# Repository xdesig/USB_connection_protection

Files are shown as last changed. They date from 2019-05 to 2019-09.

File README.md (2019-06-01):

# USB connection protection  V 001

This circuit is responsible for the protection against excessive consumption by resettable fuse and protection against overvoltage. to protect each I / O pin from high voltages, from ESD for electronic equipment that can be connected via the USB bus.
Rugged diodes (TVS Diode Arrays (SPA® Diodes) littelfuse) can safely absorb repetitive strokes of ESD at the maximum level specified in the international standard IEC 61000-4-2 (Level 4, contact discharge of ± 8 kV) without performance degradation. Their very low load capacity also makes them ideal for protecting high speed signal pins such as HDMI, DVI, USB2.0 and IEEE 1394.

Protects both the computer and the peripheral. I designed this small circuit when an improper mount of a driver in a RAMPS, burned the USB of the Laptop :-(

Buy PCB in [PCBWAY]

Components: Electronics Lcsc

[USB Female]

[USB Male]

PTC Resettable fuse [SMD1206B050TF]

TVS Littelfuse [SP3003-02JTG]

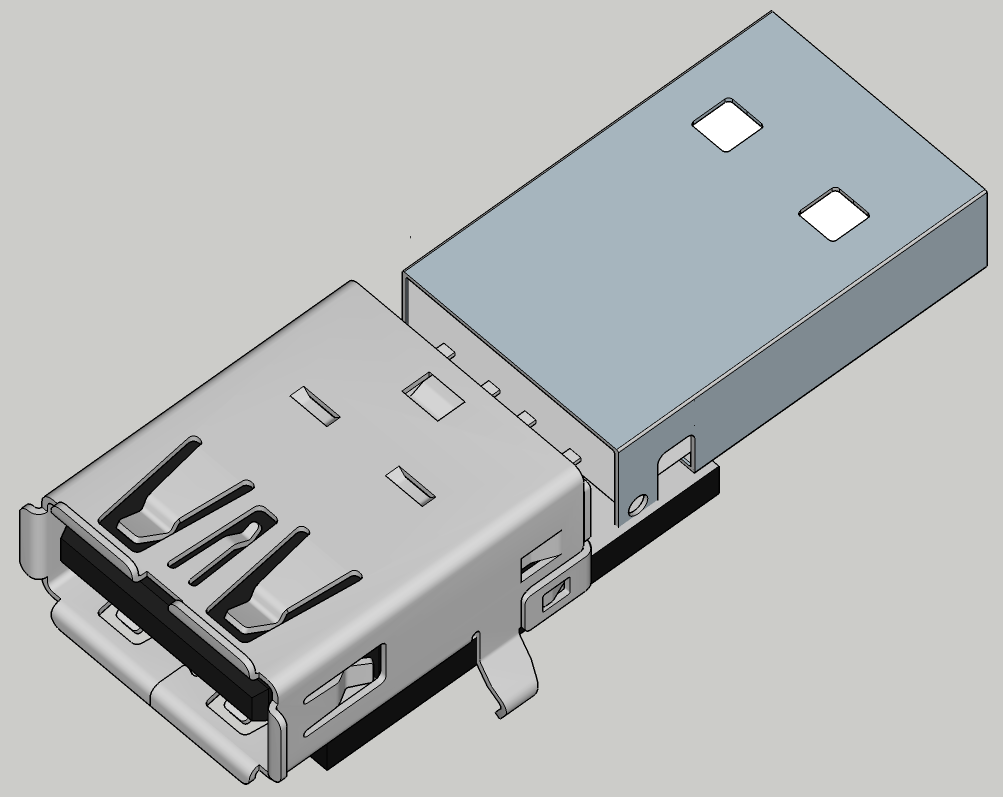
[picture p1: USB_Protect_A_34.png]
Render

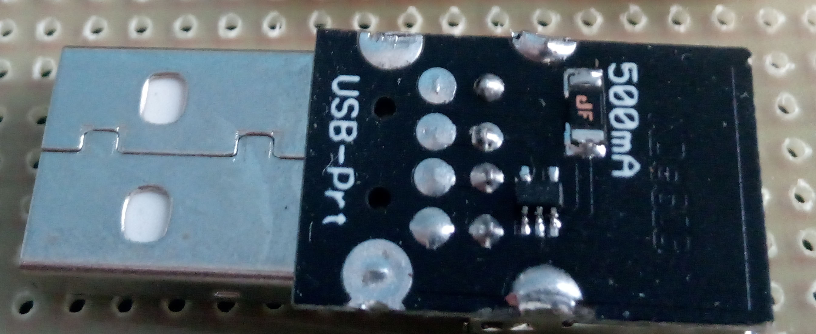
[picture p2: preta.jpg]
Real


## Author and license
* Author: [XDeSIG][TWI01]
* License: [Attribution-ShareAlike 4.0 International] [CCBY-SA4.0]

<!-- links -->

[CCBY-SA4.0]: http://creativecommons.org/licenses/by-sa/4.0/
[TWI01]: https://twitter.com/xdesig
[RENDER]: USB_Protect_A_34.png
[Real]: preta.jpg
[PCBWAY]: https://www.pcbway.com/project/shareproject/USB_connection_protection.html
[USB Female]: https://lcsc.com/product-detail/USB-Connectors_Jing-Extension-of-the-Electronic-Co-LCSC-USB-A-F900-14-1-Not-high-temperature_C2344.html
[USB Male]: https://lcsc.com/product-detail/USB-Connectors_Atype-USBMale-head-USB-05_C112454.html
[SMD1206B050TF]: https://lcsc.com/product-detail/Others_Brightking-Elec-TAIWAN-SMD1206B025TF_C269112.html
[SP3003-02JTG]: https://lcsc.com/product-detail/TVS_Littelfuse_SP3003-02JTG_SP3003-02JTG_C151302.html

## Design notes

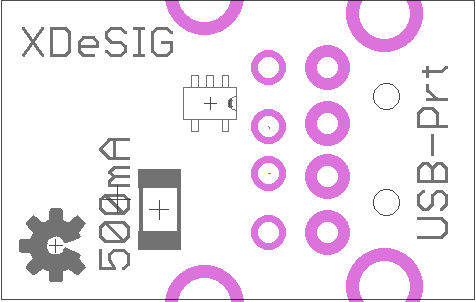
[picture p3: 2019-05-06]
USB_Protect_A_SB.png

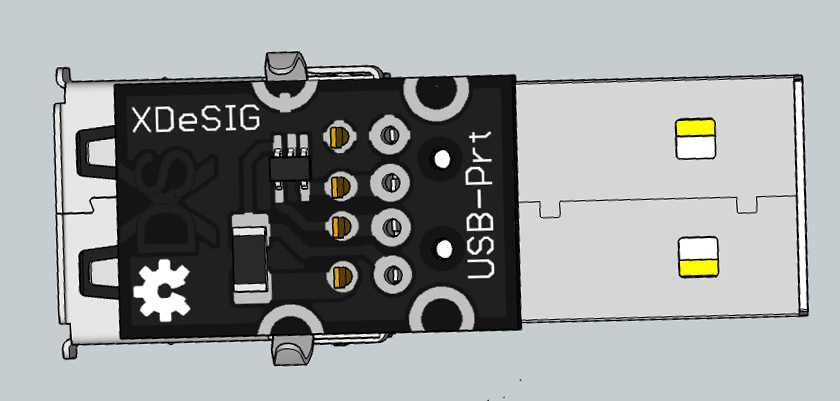
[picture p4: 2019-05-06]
USB_Protect_A_Bot.png

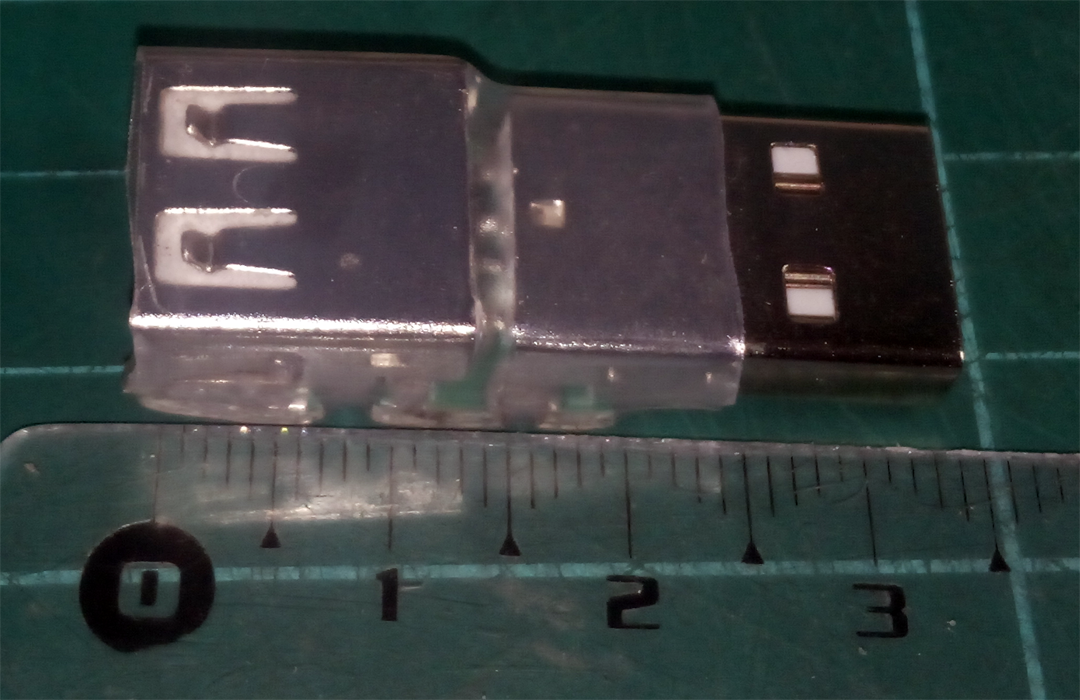
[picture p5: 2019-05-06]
USB_Protect_A_PTOP.png

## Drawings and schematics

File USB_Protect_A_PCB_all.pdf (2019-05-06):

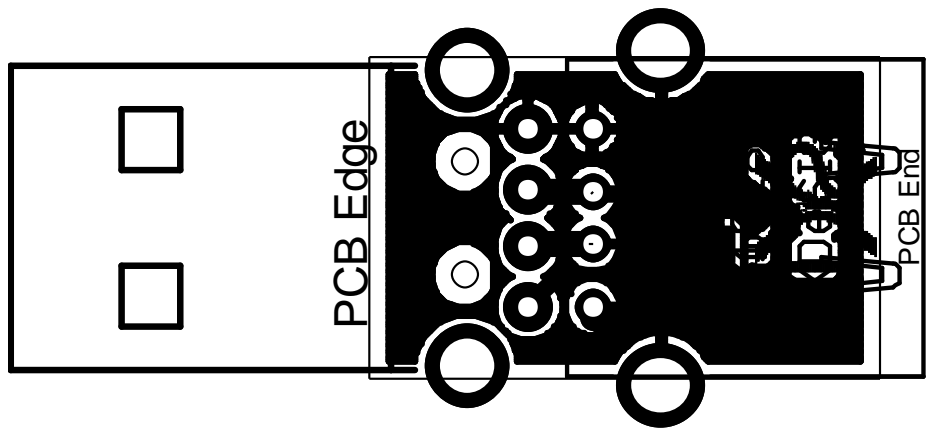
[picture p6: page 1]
PCB Edge; PCB End

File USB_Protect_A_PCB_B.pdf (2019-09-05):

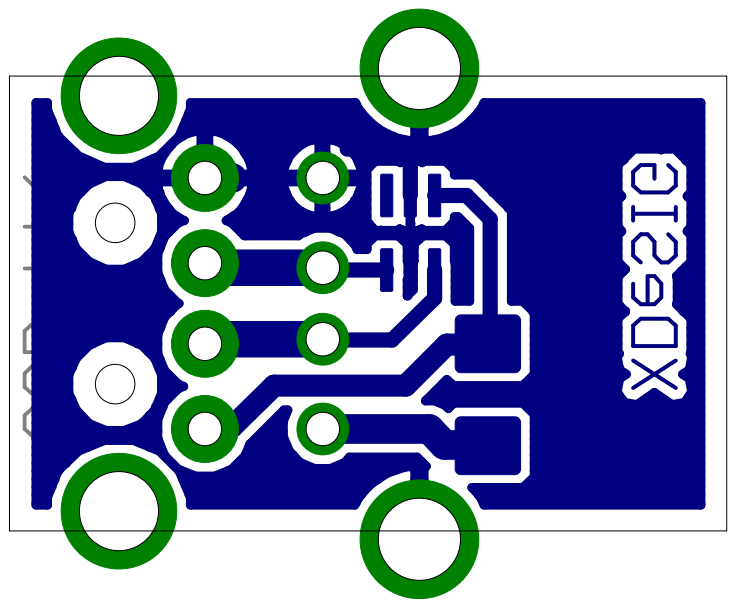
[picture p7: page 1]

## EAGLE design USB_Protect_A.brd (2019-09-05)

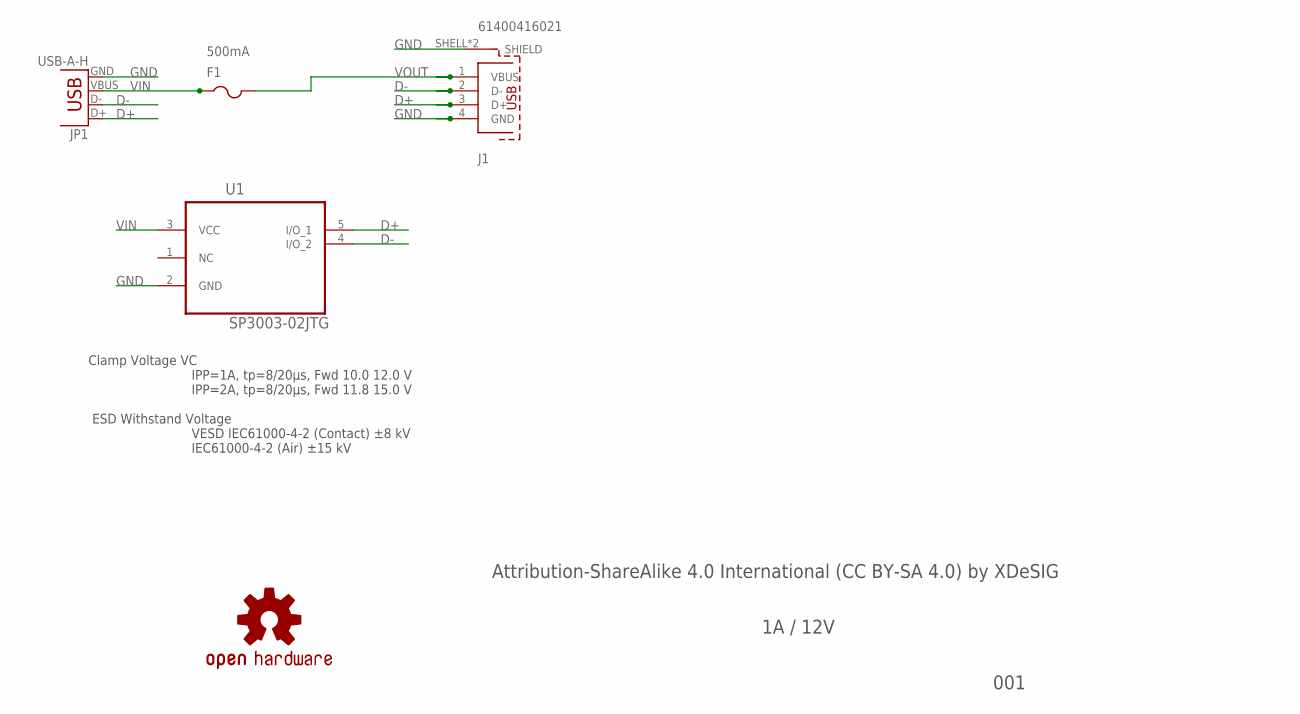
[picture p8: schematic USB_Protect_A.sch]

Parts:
F1: 500mA; R1206
J1: 61400416021
JP1: USB-A-H
LOGO1: OSHW-LOGOS; ESCORNA_LBRESCORNA_CPU_2_10_SPARKFUN-AESTHETICS_OSHW-LOGO-S
U1: SP3003-02JTG; SOT65P220X110-5N

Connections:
D+: J1.3 (D+), JP1.D+, U1.5 (I/O_1)
D-: J1.2 (D-), JP1.D-, U1.4 (I/O_2)
GND: J1.4 (GND), J1.SHELL (SHIELD), J1.SHELL1 (SHIELD), JP1.GND, U1.2 (GND)
VIN: F1.1, JP1.VBUS, U1.3 (VCC)
VOUT: F1.2, J1.1 (VBUS)

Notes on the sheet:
Clamp Voltage VC IPP=1A, tp=8/20µs, Fwd 10.0 12.0 V IPP=2A, tp=8/20µs, Fwd 11.8 15.0 V ESD Withstand Voltage VESD IEC61000-4-2 (Contact) ±8 kV IEC61000-4-2 (Air) ±15 kV
1A / 12V
Attribution-ShareAlike 4.0 International (CC BY-SA 4.0) by XDeSIG
001

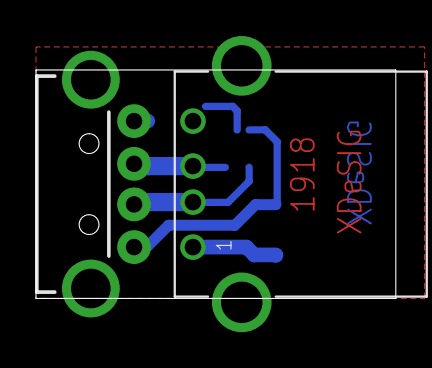
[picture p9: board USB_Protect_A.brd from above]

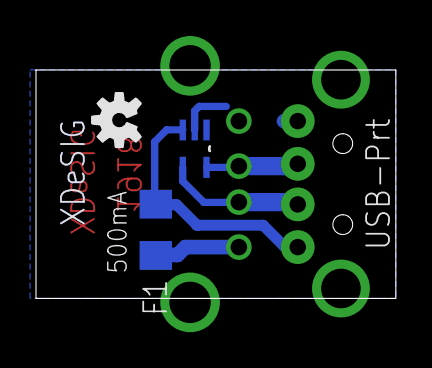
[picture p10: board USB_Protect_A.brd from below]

Board: 2 copper layers, 20.0 x 12.7 mm, 5 parts (3 on the bottom side), 5 nets.

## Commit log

2019-05-06 Inital commit
    Public
    [USB_Protect_A.sch]
2019-05-06 Revert "Inital commit"
    This reverts commit 5c7089dacc69489dbe68ce8c657147b81196c9f3.
    [USB_Protect_A.sch]
2019-05-06 Initial
    Initial commit
    [USB_Protect_A.sch]
2019-09-05 Update
    Update details
    [USB_Protect_A.brd, USB_Protect_A.sch]

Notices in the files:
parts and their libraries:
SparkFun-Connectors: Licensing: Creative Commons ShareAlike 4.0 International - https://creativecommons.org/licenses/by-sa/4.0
